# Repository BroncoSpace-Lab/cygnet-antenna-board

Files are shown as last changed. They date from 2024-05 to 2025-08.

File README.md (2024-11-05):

# antenna-board

This repo contains the KiCAD files for the PROVES Kit Antenna Board. This board currently goes on the +Z endcap of the satellite and hosts the antennas, interfacing ports, and some other support circuitry!

## antenna_top_cap_board_v1a
This antenna board is a reformat of the V1 Antenna Board that consolidates a bunch of the 2pos Picolock and STEMMA connectors into a single connector that runs back to the V3b EPS Board. We are probably going to leapfrog this version to land on V2 which fundementally changes things about the antenna feed path. 

## antenna_top_cap_v2
This version of the antenna top cap featuers major changes to the antenna feed path and debug passthroughs. Notable features are as follows: 
- Updated Balun Part Number (no longer sucks! still sucks to solder though)
- Addition of 12-pos and 5-pos Battery Board and Flight Controller Board debug connectors.

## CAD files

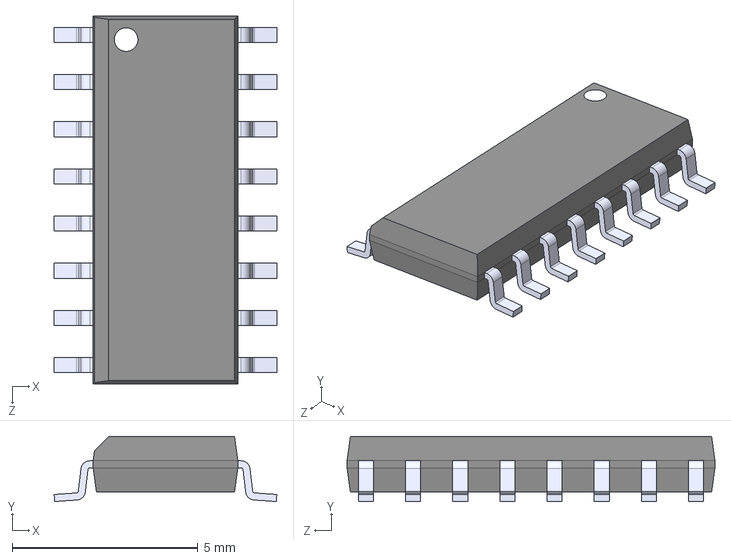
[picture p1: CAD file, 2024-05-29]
antenna_top_cap_v2b_cygnet_special/Extra Libraries Folder/CD74HC4050M96/CD74HC4050M96.step
5.99 x 1.75 x 9.91 mm

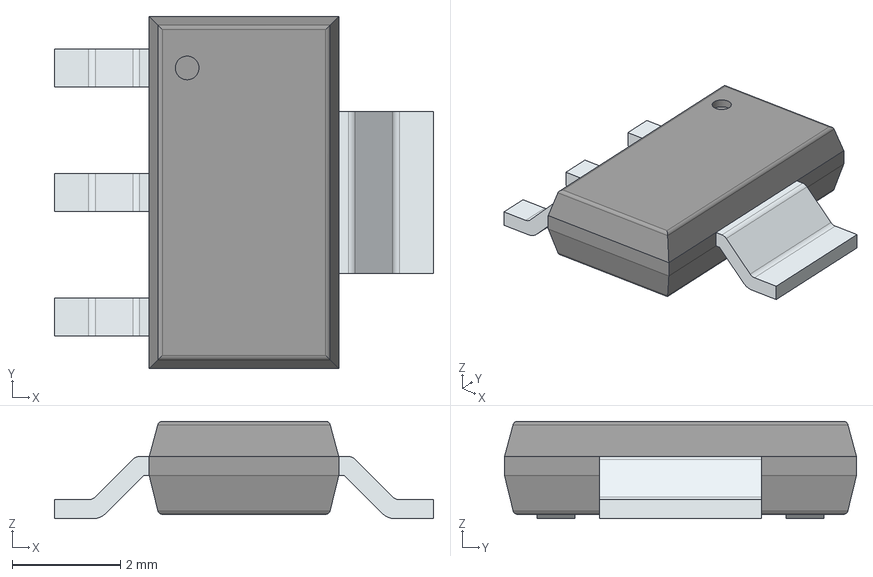
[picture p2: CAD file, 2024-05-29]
antenna_top_cap_v2b_cygnet_special/Extra Libraries Folder/LIB_AZ1117CH-3.3TRG1 (1)/AZ1117CH-3.3TRG1/3D/AZ1117CH-3.3TRG1.stp
7.00 x 6.50 x 1.80 mm
PinsArrayL
FilletPinR

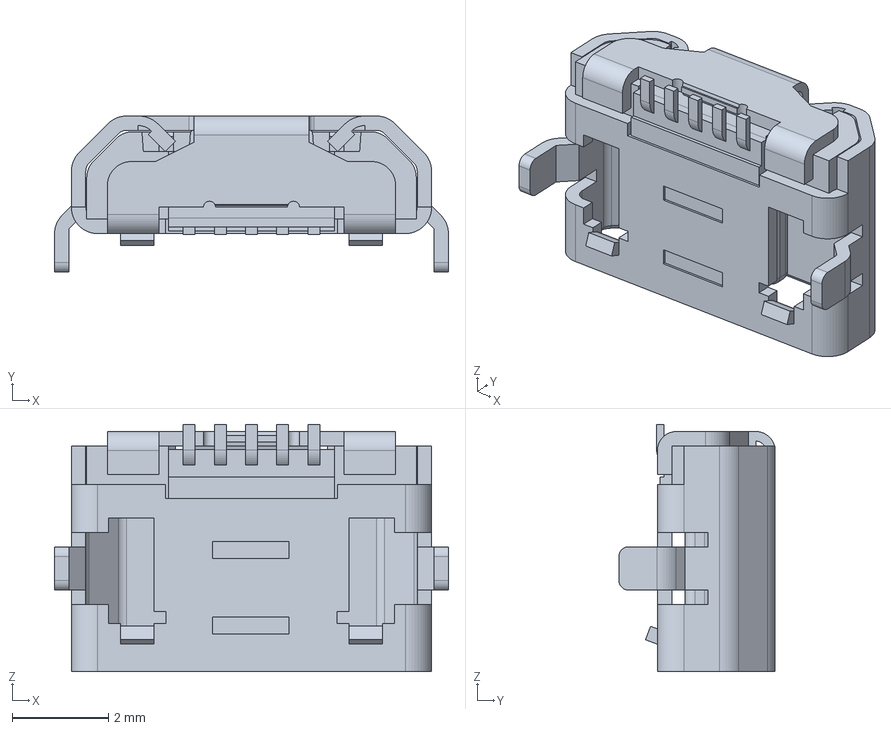
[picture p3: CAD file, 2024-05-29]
antenna_top_cap_v2b_cygnet_special/Extra Libraries Folder/105164-0001 (1)/105164-0001.step
8.20 x 3.25 x 5.15 mm

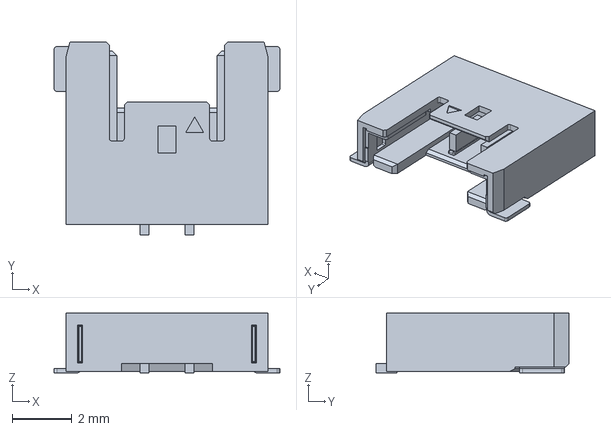
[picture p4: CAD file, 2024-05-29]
antenna_top_cap_v2b_cygnet_special/Extra Libraries Folder/504050-0291/504050-0291.step
7.55 x 6.44 x 2.00 mm

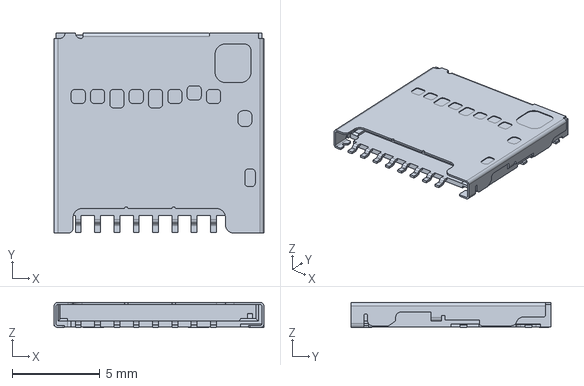
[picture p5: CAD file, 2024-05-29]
antenna_top_cap_v2b_cygnet_special/Extra Libraries Folder/LIB_104031-0811/104031-0811/3D/104031-0811.stp
11.9 x 11.4 x 1.45 mm

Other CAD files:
antenna_top_cap_v2b_cygnet_special/Extra Libraries Folder/LIB_104031-0811/104031-0811/Allegro/1040310811.psm
antenna_top_cap_v2b_cygnet_special/Extra Libraries Folder/LIB_104031-0811/104031-0811/DEHDL/104031_0811/chips/chips.prt
antenna_top_cap_v2b_cygnet_special/Extra Libraries Folder/LIB_AZ1117CH-3.3TRG1 (1)/AZ1117CH-3.3TRG1/Allegro/sot230p700x180-4n.psm
antenna_top_cap_v2b_cygnet_special/Extra Libraries Folder/LIB_AZ1117CH-3.3TRG1 (1)/AZ1117CH-3.3TRG1/DEHDL/az1117ch_3.3trg1/chips/chips.prt

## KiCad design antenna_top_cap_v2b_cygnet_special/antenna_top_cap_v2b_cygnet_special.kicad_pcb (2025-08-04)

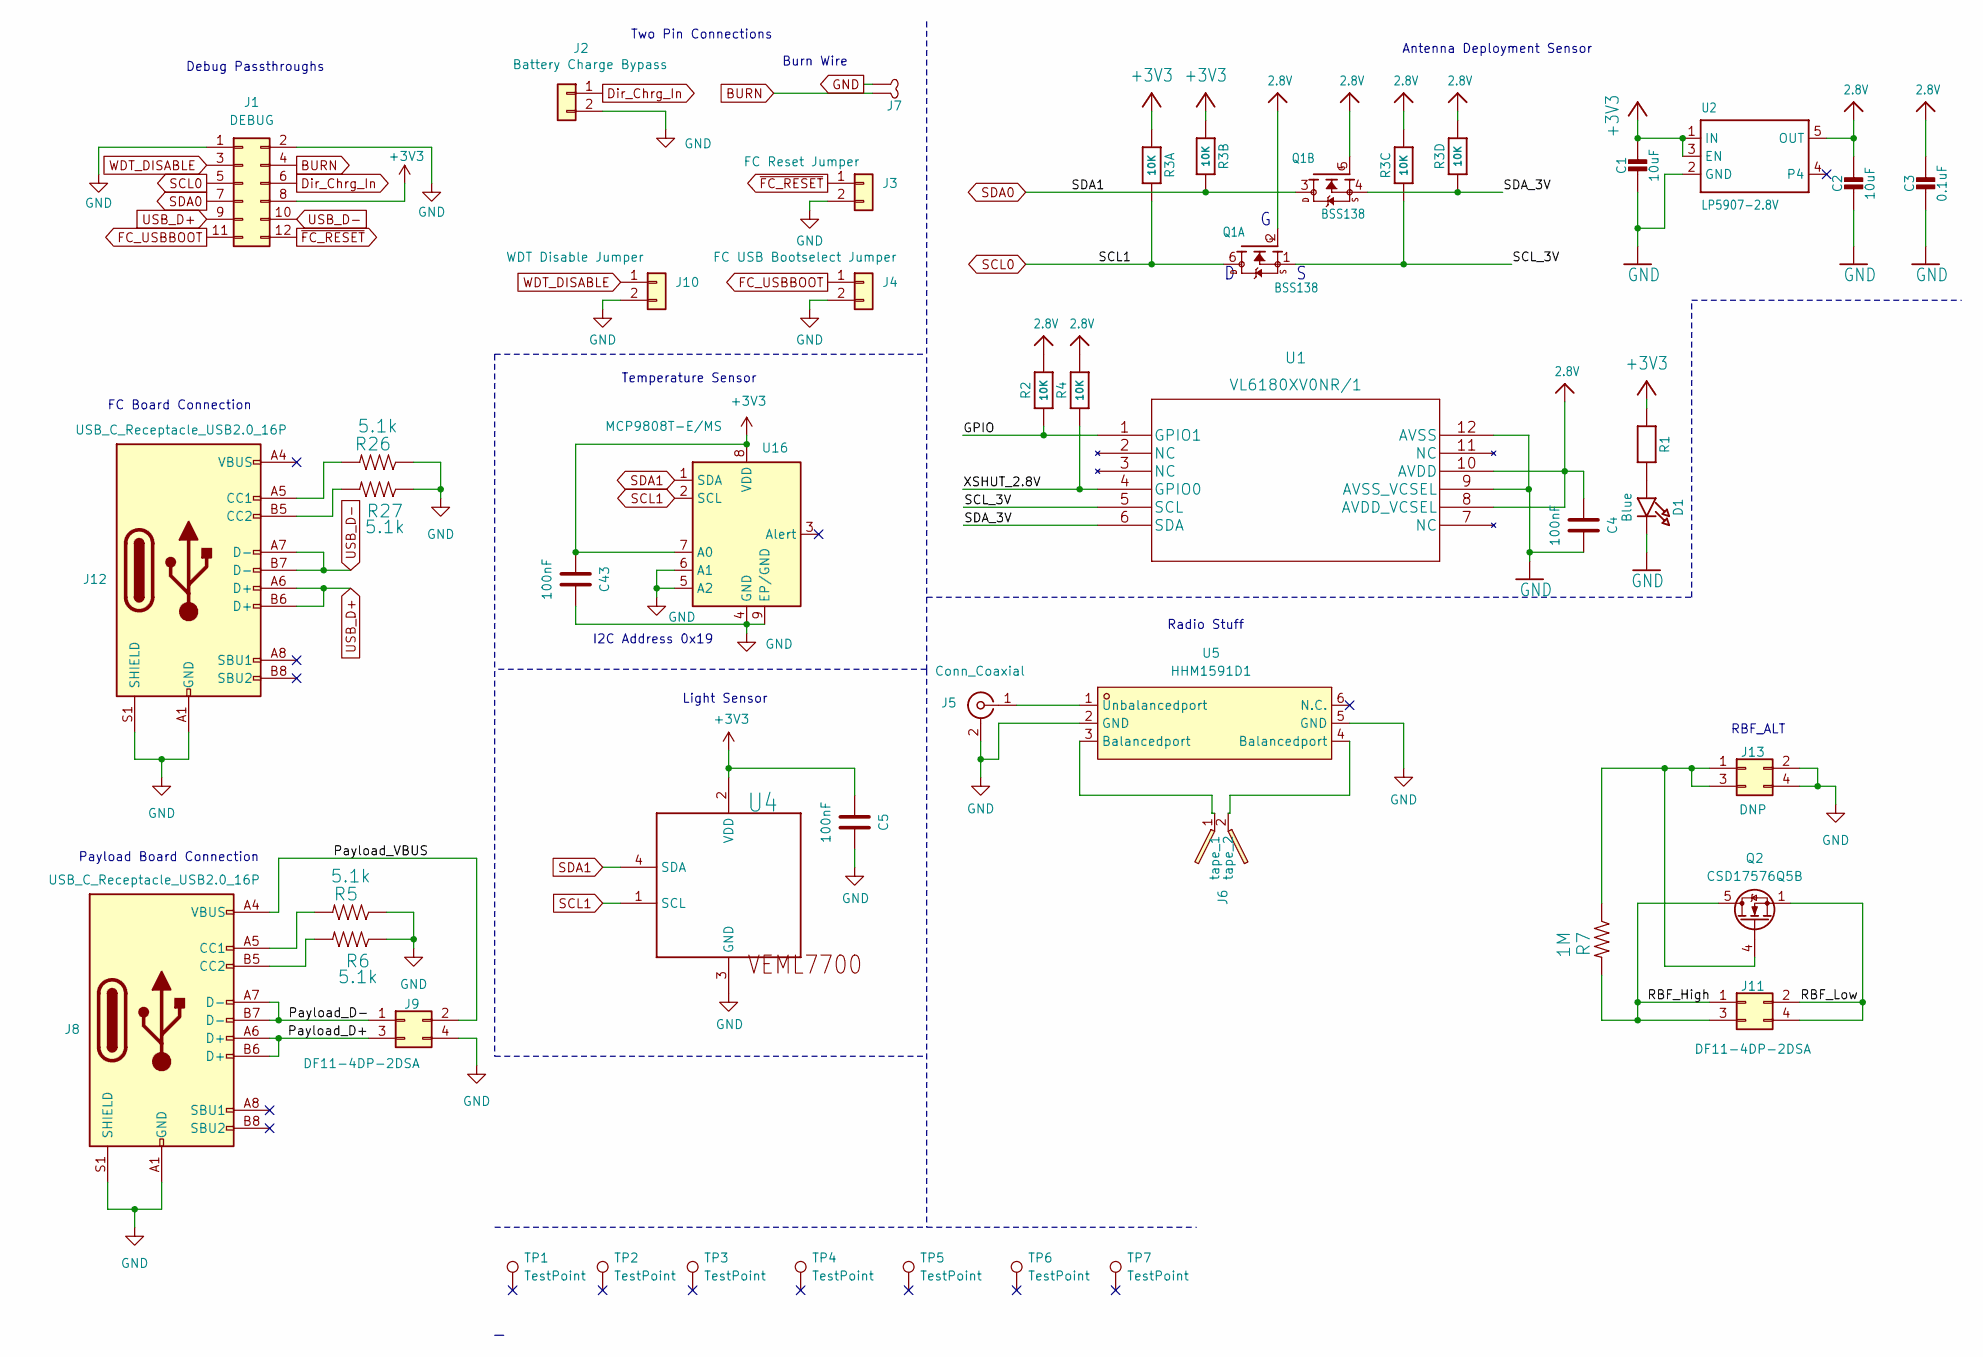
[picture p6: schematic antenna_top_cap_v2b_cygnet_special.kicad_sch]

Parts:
C1, C2: 10uF; C_0805_2012Metric
C3: 0.1uF; C_0603_1608Metric
C4, C5, C43: 100nF; C_0805_2012Metric
D1: Blue; LED_0603_1608Metric
J1: DEBUG; Hirose_DF11-12DP-2DSA_2x06_P2.00mm_Vertical
J2: Battery Charge Bypass; PinHeader_1x02_P2.54mm_Vertical
J3: FC Reset Jumper; PinHeader_1x02_P2.54mm_Vertical
J4: FC USB Bootselect Jumper; PinHeader_1x02_P2.54mm_Vertical
J5: Conn_Coaxial; SMA_Amphenol_901-144_Vertical
J6: Tape_Measure_Antenna
J7: Burn_Wire
J8, J12: USB_C_Receptacle_USB2.0_16P; USB_C_Receptacle_HRO_TYPE-C-31-M-12
J9, J11: DF11-4DP-2DSA; Hirose_DF11-4DP-2DSA_2x02_P2.00mm_Vertical
J10: WDT Disable Jumper; PinHeader_1x02_P2.54mm_Vertical
J13: DNP; Hirose_DF11-4DP-2DSA_2x02_P2.00mm_Vertical
Q1: BSS138; SOT-363_SC-70-6
Q2: CSD17576Q5B; TDSON-8-1
R1: 10k; R_0402_1005Metric
R2, R4: 10K; R_0603_1608Metric
R3: 10K; R_Array_Convex_4x0603
R5, R6, R26, R27: 5.1k; R_0603_1608Metric
R7: 1M; R_0603_1608Metric
TP1, TP2, TP3, TP4, TP5, TP6, TP7: TestPoint; MountingHole_2.7mm_M2.5_Pad
U1: VL6180XV0NR/1; VL6180
U2: LP5907-2.8V; SOT-23-5
U4: VEML7700; XDCR_VEML7700-TT
U5: HHM1591D1; XFMR-SMD_HHM1591D1; LCSC Part C74209
U16: MCP9808T-E/MS; MSOP-8-1EP_3x3mm_P0.65mm_EP1.5x1.8mm_ThermalVias

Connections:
2.8V: C2.1, C3.1, C4.1, Q1.2 (G), Q1.5 (G), R2.2, R3.3 (1), R3.4 (1), R4.2, U1.8 (AVDD_VCSEL), U1.10 (AVDD), U2.5 (OUT)
+3V3: C1.1, C5.1, C43.1, J1.8, R1.1, R3.1, R3.2 (1), U2.1 (IN), U2.3 (EN), U4.2 (VDD), U16.7 (A0), U16.8 (VDD)
/GPIO: R2.1, U1.1 (GPIO1)
/Payload_D+: J8.A6 (D+), J8.B6 (D+), J9.3
/Payload_D-: J8.A7 (D-), J8.B7 (D-), J9.1
/Payload_VBUS: J8.A4 (VBUS), J8.A9 (VBUS), J8.B4 (VBUS), J8.B9 (VBUS), J9.2
/RBF_High: J11.1, J11.3, Q2.5 (D), R7.2
/RBF_Low: J11.2, J11.4, Q2.1 (S), Q2.2 (S), Q2.3 (S)
/SCL_3V: Q1.1 (S), R3.6 (2), U1.5 (SCL)
/SDA_3V: Q1.4 (S), R3.5 (2), U1.6 (SDA)
/XSHUT_2.8V: R4.1, U1.4 (GPIO0)
BURN: J1.4, J7.1 (Power)
Dir_Chrg_In: J1.6, J2.1
FC_USBBOOT: J1.11, J4.1
GND: C1.2, C2.2, C3.2, C4.2, C5.2, C43.2, D1.2 (C), J1.1, J1.2, J2.2, J3.2, J4.2, J5.2 (Ext), J7.2 (GND), J8.A1 (GND), J8.A12 (GND), J8.B1 (GND), J8.B12 (GND), J8.S1 (SHIELD), J9.4, J10.2, J12.A1 (GND), J12.A12 (GND), J12.B1 (GND), J12.B12 (GND), J12.S1 (SHIELD), J13.2, J13.4, R5.1, R6.1, R26.1, R27.1, U1.9 (AVSS_VCSEL), U1.12 (AVSS), U2.2 (GND), U4.3 (GND), U5.2 (GND), U5.5 (GND), U16.4 (GND), U16.5 (A2), U16.6 (A1), U16.9 (EP/GND)
unnamed: D1.1 (A), R1.2
unnamed: J5.1 (In), U5.1 (Unbalancedport)
unnamed: J6.1 (tape), U5.3 (Balancedport)
unnamed: J6.2 (tape), U5.4 (Balancedport)
unnamed: J8.A5 (CC1), R5.2
unnamed: J8.B5 (CC2), R6.2
unnamed: J12.A5 (CC1), R26.2
unnamed: J12.B5 (CC2), R27.2
unnamed: J13.1, J13.3, Q2.4 (G), R7.1
SCL0: J1.5, Q1.6 (D), R3.8 (2), U4.1 (SCL), U16.2 (SCL)
SDA0: J1.7, Q1.3 (D), R3.7 (2), U4.4 (SDA), U16.1 (SDA)
USB_D+: J1.9, J12.A6 (D+), J12.B6 (D+)
USB_D-: J1.10, J12.A7 (D-), J12.B7 (D-)
WDT_DISABLE: J1.3, J10.1
~FC_RESET: J1.12, J3.1

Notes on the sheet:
Light Sensor
Two Pin Connections
I2C Address 0x19
Antenna Deployment Sensor
Radio Stuff
Debug Passthroughs
FC Board Connection
RBF_ALT
Payload Board Connection
Burn Wire
Temperature Sensor

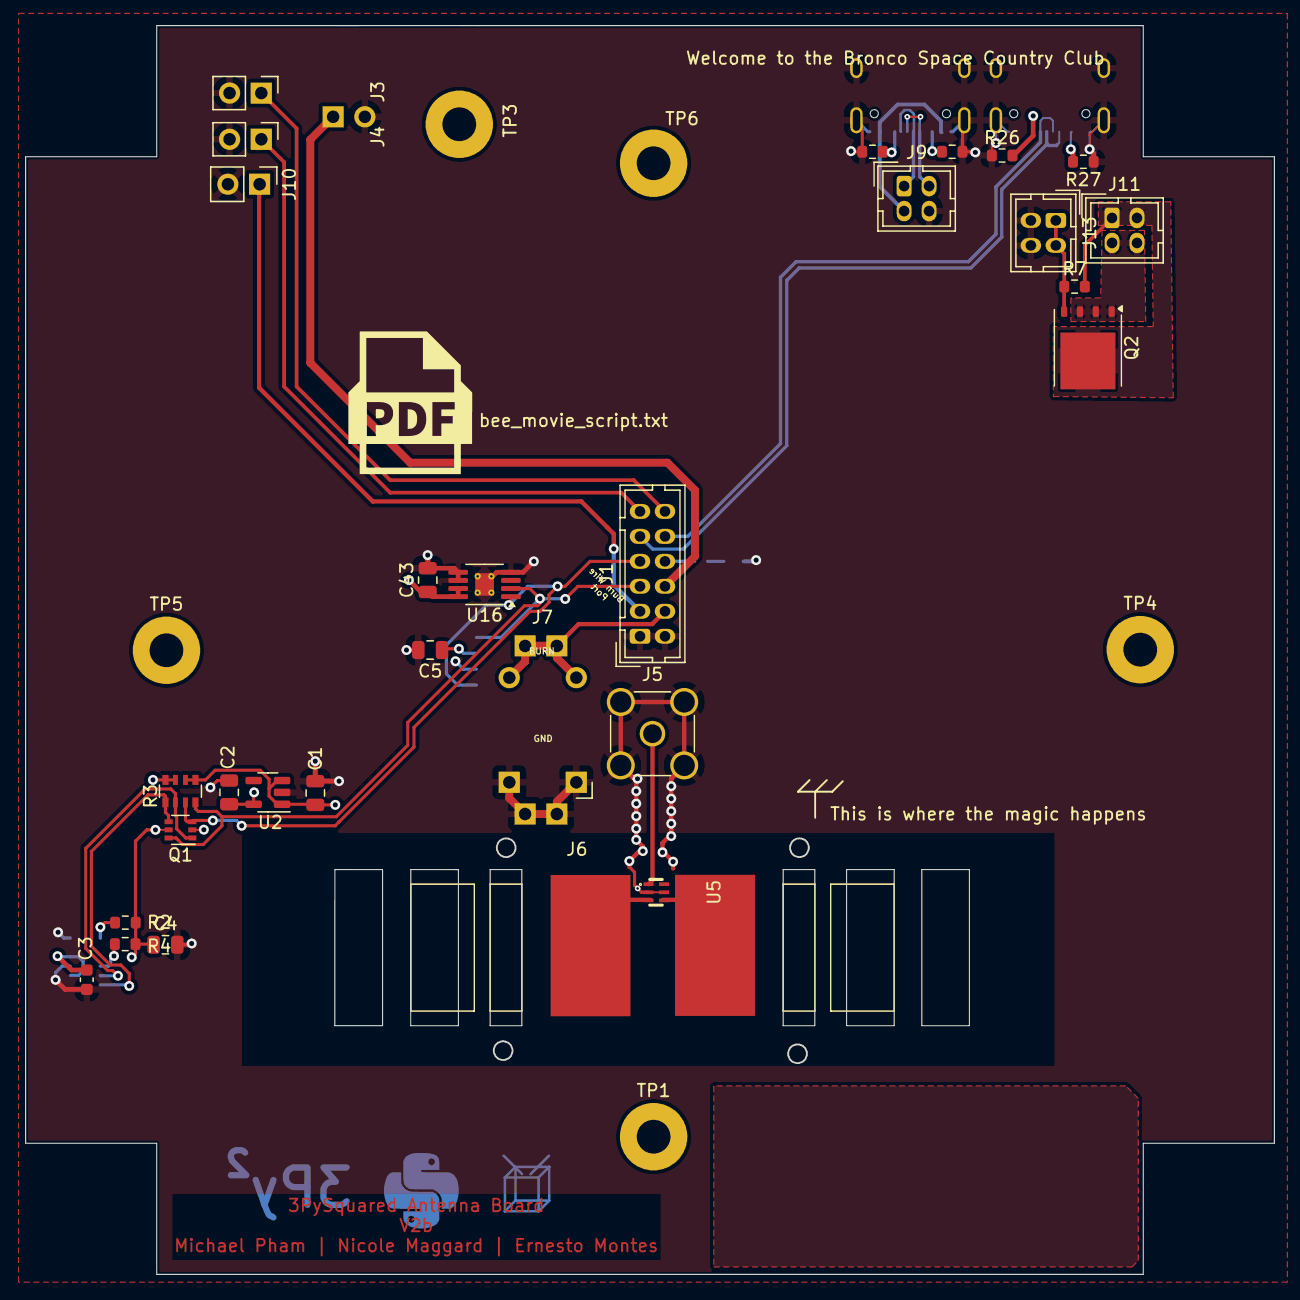
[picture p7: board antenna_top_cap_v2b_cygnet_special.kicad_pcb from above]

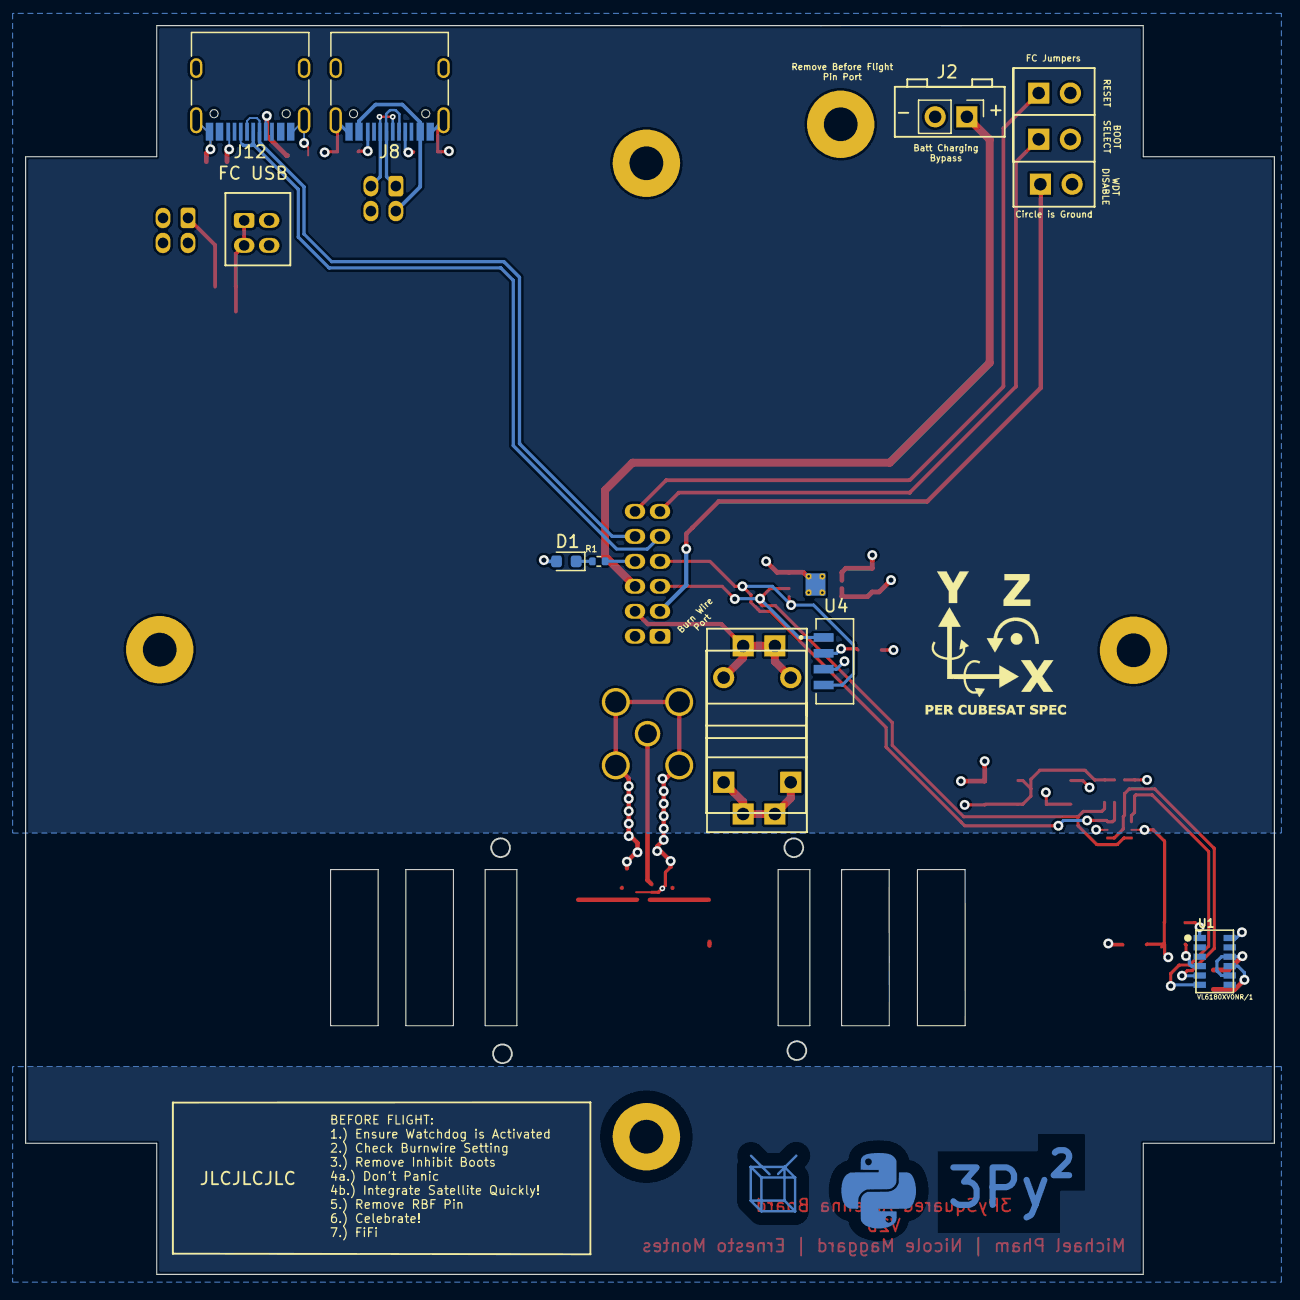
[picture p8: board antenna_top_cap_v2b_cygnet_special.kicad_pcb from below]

Board: 2 copper layers, 100.0 x 100.0 mm, 41 parts (7 on the bottom side), 30 nets.

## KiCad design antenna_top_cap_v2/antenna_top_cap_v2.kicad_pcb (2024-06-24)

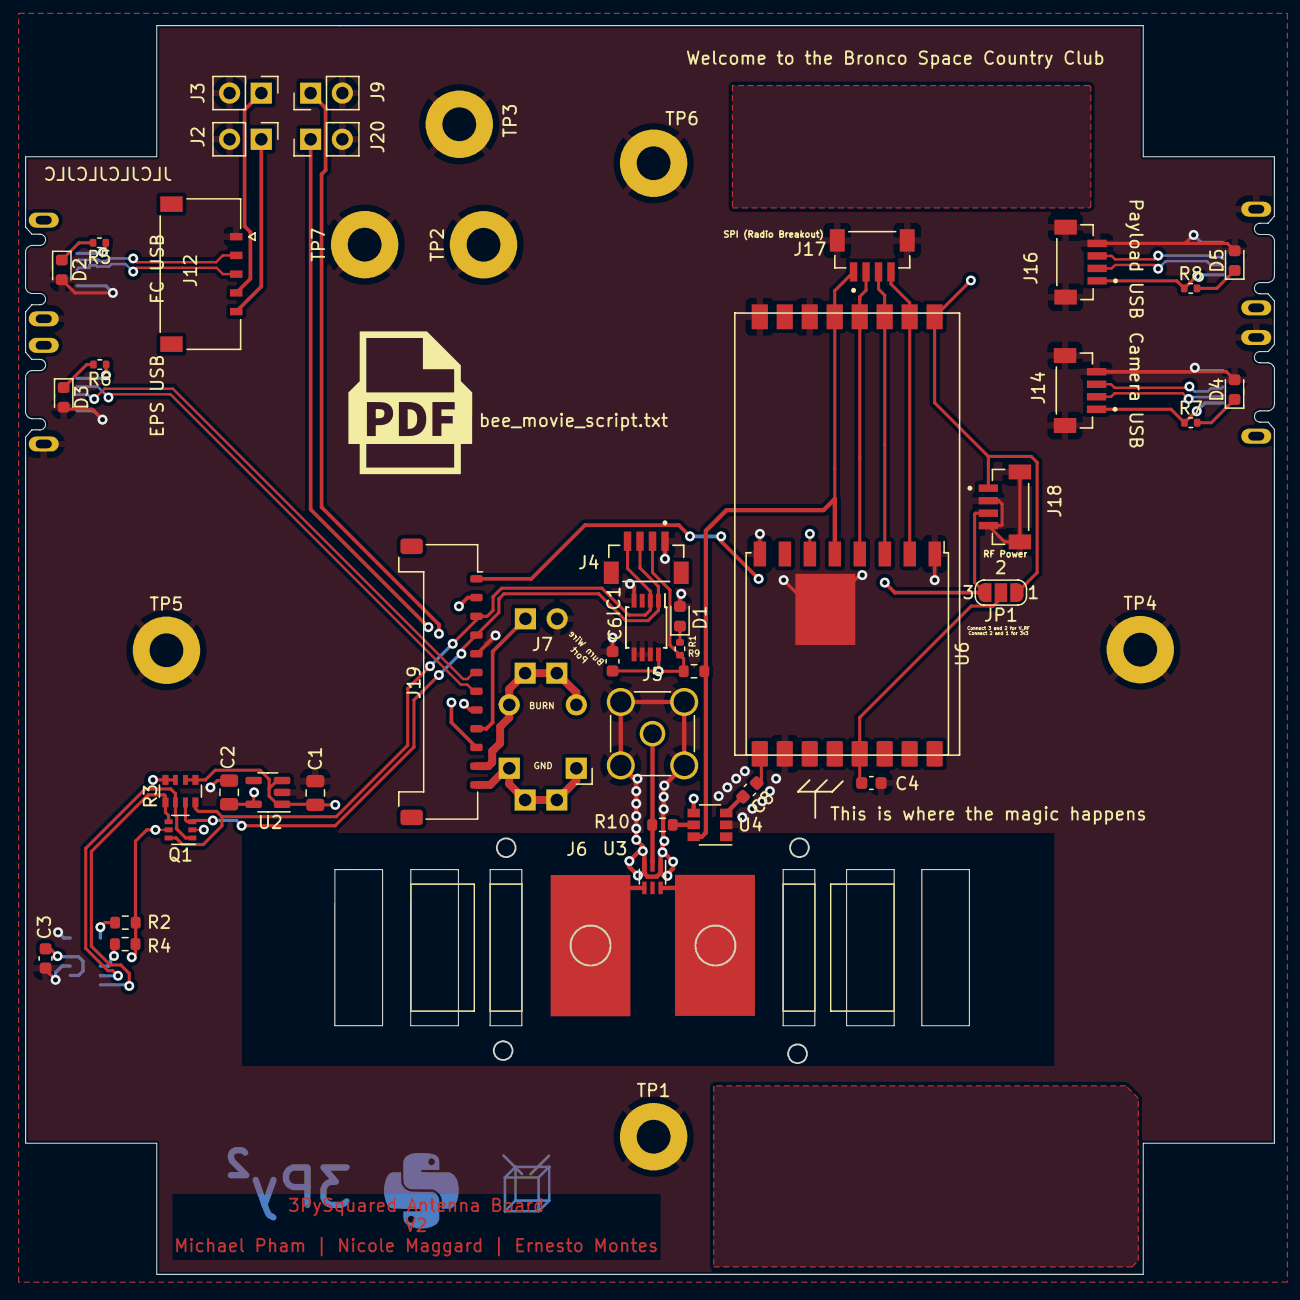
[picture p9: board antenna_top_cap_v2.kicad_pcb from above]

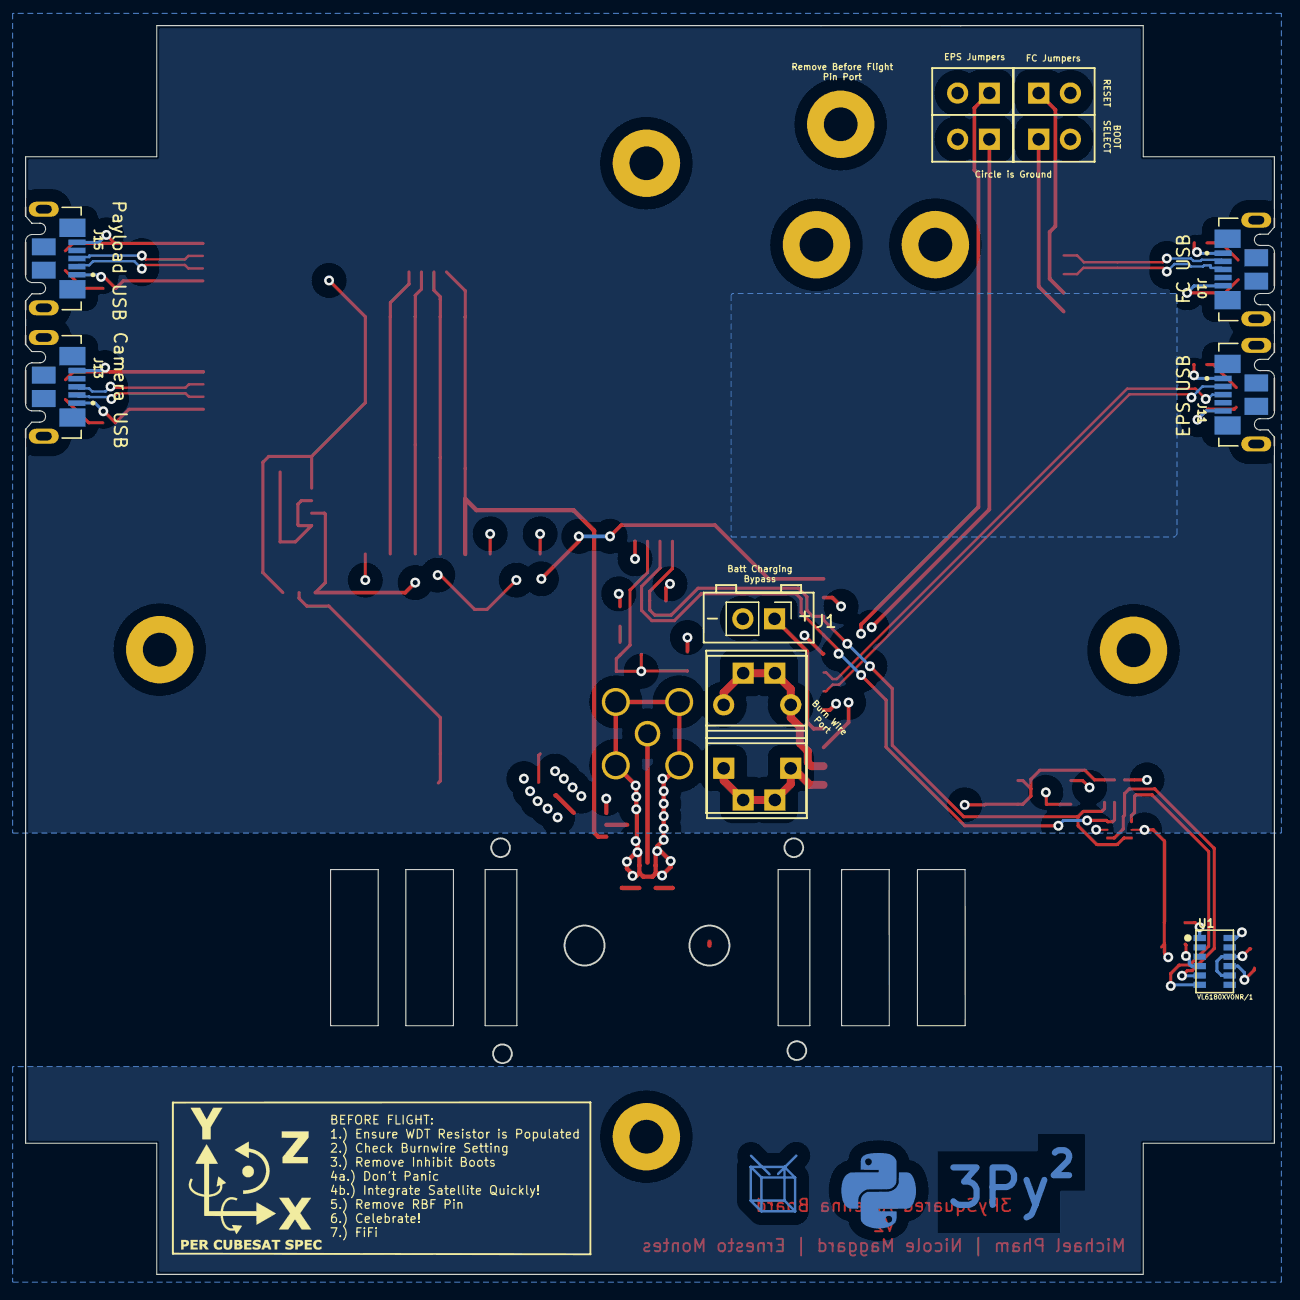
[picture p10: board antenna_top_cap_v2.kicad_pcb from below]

Board: 4 copper layers, 100.0 x 100.0 mm, 56 parts (6 on the bottom side), 45 nets.

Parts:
C1, C2: 10uF; C_0805_2012Metric
C3: 0.1uF; C_0603_1608Metric
C4: 10uF; C_0603_1608Metric
C6: 100nf; C_0603_1608Metric
C8: 100pf; C_0603_1608Metric
D1, D2, D3, D4, D5: Blue; LED_0603_1608Metric
IC1: PCT2075DP,118; TSSOP-8_3x3mm_P0.65mm
J1: Battery Charge Bypass; PinHeader_1x02_P2.54mm_Vertical
J2: EPS USB Bootselect Jumper; PinHeader_1x02_P2.54mm_Vertical
J3: EPS Reset Jumper; PinHeader_1x02_P2.54mm_Vertical
J4, J14, J16, J17, J18: BM04B-SRSS-TB(LF)(SN); JST_BM04B-SRSS-TB(LF)(SN)
J5: Conn_Coaxial; SMA_Amphenol_901-144_Vertical
J6: Tape_Measure_Antenna
J7: Burn_Wire
J9: FC Reset Jumper; PinHeader_1x02_P2.54mm_Vertical
J10: USB_B_Micro_FC; MOLEX_105164-0001(round)
J11: USB_B_Micro_EPS; MOLEX_105164-0001(round)
J12: FC Board Connector; MOLEX_5040500591
J13, J15: USB_B_Micro; MOLEX_105164-0001(round)
J19: EPS Board Connector; Molex_Pico-Lock_504050-1291_1x12-1MP_P1.50mm_Horizontal
J20: FC USB Bootselect Jumper; PinHeader_1x02_P2.54mm_Vertical
JP1: SolderJumper_3_Open; SolderJumper-3_P1.3mm_Open_RoundedPad1.0x1.5mm_NumberLabels
Q1: BSS138; SOT-363_SC-70-6
R1, R5, R6, R7, R8: 1K; R_0402_1005Metric
R2, R4: 10K; R_0603_1608Metric
R3: 10K; R_Array_Convex_4x0603
R9: 10k; R_0603_1608Metric
R10: DNI; R_0603_1608Metric
TP1, TP2, TP3, TP4, TP5, TP6, TP7: TestPoint; MountingHole_2.7mm_M2.5_Pad
U1: VL6180XV0NR/1; VL6180
U2: LP5907-2.8V; SOT-23-5
U3: NCS1.5-232+; Balun_Johanson_0896BM15A0001
U4: AS193-73LF; SuperSOT-6
U5: RFM98PW
U6: RFM9xBreakout; HOPERF_RFM95W_SMD

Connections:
2.8V: C2.1, C3.1, Q1.2 (G), Q1.5 (G), R2.2, R3.3 (1), R3.4 (1), R4.2, U1.8 (AVDD_VCSEL), U1.10 (AVDD), U2.5 (OUT)
+3V3: C1.1, C6.1, IC1.8 (VCC), J4.2, J18.1, J19.2, JP1.1 (A), R1.1, R3.1, R3.2 (1), R9.1, U2.1 (IN), U2.3 (EN), U4.4 (V2), U5.9 (3.3V), U6.6 (~RESET)
/2d+: J13.3 (D+), J14.3
/2d-: J13.2 (D-), J14.2
/3d+: J15.3 (D+), J16.3
/3d-: J15.2 (D-), J16.2
/GPIO: R2.1, U1.1 (GPIO1)
/SCL_3V: Q1.1 (S), R3.6 (2), U1.5 (SCL)
/SDA_3V: Q1.4 (S), R3.5 (2), U1.6 (SDA)
/XSHUT_2.8V: R4.1, U1.4 (GPIO0)
BURN: J7.1 (Power), J19.11
BURN_GND: J7.2 (GND), J19.12
Balun: R10.1, U4.5 (output)
Dir_Chrg_In: J1.1, J19.9
EPS_USBBOOT: J2.1, J19.10
EPS_USB_D+: J11.3 (D+), J19.6
EPS_USB_D-: J11.2 (D-), J19.7
FC_USBBOOT: J12.5, J20.1
FC_USB_D+: J10.3 (D+), J12.3
FC_USB_D-: J10.2 (D-), J12.2
GND: C1.2, C2.2, C3.2, C4.1, C6.2, D1.2 (C), D2.2 (C), D3.2 (C), D4.2 (C), D5.2 (C), IC1.4 (GND), IC1.5 (A2), IC1.6 (A1), IC1.7 (A0), J1.2, J2.2, J3.2, J4.1, J5.2 (Ext), J9.2, J10.5 (GND), J10.SH1 (Shield), J11.5 (GND), J11.SH1 (Shield), J12.1, J13.5 (GND), J13.SH1 (Shield), J14.4, J14.S1 (SHIELD), J14.S2 (SHIELD), J15.5 (GND), J15.SH1 (Shield), J16.4, J16.S1 (SHIELD), J16.S2 (SHIELD), J17.S1 (SHIELD), J17.S2 (SHIELD), J18.2, J18.4, J18.S1 (SHIELD), J18.S2 (SHIELD), J19.5, J20.2, TP1.1, TP2.1, TP3.1, TP4.1, TP5.1, TP6.1, TP7.1, U1.9 (AVSS_VCSEL), U1.12 (AVSS), U2.2 (GND), U3.1 (GND), U3.3 (GND), U4.2 (GND), U5.2 (GND), U5.14 (RESET), U5.16 (GND), U5.17 (GND), U6.1 (GND), U6.8 (GND), U6.10 (GND)
unnamed: D1.1 (A), R1.2
unnamed: D2.1 (A), R5.2
unnamed: D3.1 (A), R6.2
unnamed: D4.1 (A), R7.2
unnamed: D5.1 (A), R8.2
unnamed: J5.1 (In), R10.2, U3.2
unnamed: J6.1 (tape), U3.4
unnamed: J6.2 (tape), U3.6
unnamed: J10.1 (VBUS), R5.1
unnamed: J11.1 (VBUS), R6.1
unnamed: J13.1 (VBUS), J14.1, R7.1
unnamed: J15.1 (VBUS), J16.1, R8.1
unnamed: C8.2, U4.3 (input2)
OUT2: C8.1, U5.1 (ANT), U6.9 (ANT)
RF_VCC: C4.2, JP1.2 (C), U5.5 (VCC), U6.13 (3V3)
SCL1: IC1.2 (SCL), J4.4, J19.3, Q1.6 (D), R3.8 (2)
SDA1: IC1.1 (SDA), J4.3, J19.4, Q1.3 (D), R3.7 (2)
SPI0_CS0: J17.1, R9.2, U4.6 (V1), U5.13 (NSS), U6.5 (CS)
SPI0_MISO: J17.4, U5.10 (MISO), U6.2 (MISO)
SPI0_MOSI: J17.3, U5.11 (MOSI), U6.3 (MOSI)
SPI0_SCK: J17.2, U5.12 (SCK), U6.4 (SCK)
V_RF: J18.3, J19.1, JP1.3 (B)
~EPS_RESET: J3.1, J19.8
~FC_RESET: J9.1, J12.4

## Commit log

2024-06-13 Started wiring with 12-pos connector for V3b
    [antenna_top_cap.kicad_pcb, antenna_top_cap.kicad_sch]
2024-06-15 Scooted IC Layout
    [antenna_top_cap.kicad_pcb]
2024-06-17 Update antenna_top_cap.kicad_pcb
    Connected Direct Change to the 12 Pin Picolock
    [antenna_top_cap.kicad_pcb]
2024-06-17 Connected USB Breakout
    [antenna_top_cap.kicad_pcb, antenna_top_cap.kicad_sch]
2024-06-17 Finished Connecting 12Pos Connections
    [antenna_top_cap.kicad_pcb, antenna_top_cap.kicad_sch]
2024-06-17 Addressed all DRC Errors
    [antenna_top_cap.kicad_pcb, antenna_top_cap.kicad_sch]
2024-06-17 Added Jumper to Aux RF Line
    Added an 0603 Jumper to break the Aux RF connection when not in use
    [antenna_top_cap.kicad_pcb, antenna_top_cap.kicad_sch]
2024-06-18 Relocated RF SPI Breakout
    [antenna_top_cap.kicad_pcb]
2024-06-18 Removed redundant trace
    For some reason there was both a 2.8V trace on the F.Cu and the B.Cu layers. Might be an artifact of the original design. The trace on the B.Cu layer was removed
    [antenna_top_cap.kicad_pcb]
2024-06-18 Updated Solder Mask
    [antenna_top_cap.kicad_pcb]
2024-06-18 Created V2 Antenna Board
    [104031-0811.SchLib, 104031-0811.stp, 1040310811.PcbLib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]
2024-06-19 Schematic Updates and Renaming a Bunch of Files
    [104031-0811.SchLib, 104031-0811.stp, 1040310811.PcbLib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]
2024-06-19 Un-nested files
    [104031-0811.SchLib, 104031-0811.stp, 1040310811.PcbLib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]
2024-06-19 Swapped Balun
    New Balun Part Number!
    Minicircuits: NCS1.5-232+
    Schematic and PCB Layout Updated
    [antenna_top_cap_v2.kicad_pcb, antenna_top_cap_v2.kicad_sch]
2024-06-19 Added Schematic Symbols for FC Debug Port
    [antenna_top_cap_v2.kicad_pcb, antenna_top_cap_v2.kicad_sch]
2024-06-20 SDA / SCL Hotfix
    See this issue: https://github.com/proveskit/antenna-board/issues/6
    [antenna_top_cap_v2.kicad_pcb, antenna_top_cap_v2.kicad_sch]
2024-06-20 Removed J8 (I2C Breakout)
    [antenna_top_cap_v2.kicad_pcb, antenna_top_cap_v2.kicad_sch]
2024-06-20 fixed the schematic
    cool beans
    [antenna_top_cap_v2.kicad_pcb, antenna_top_cap_v2.kicad_sch]
2024-06-23 Removed One of the I2C Breakouts
2024-06-23 Added mounting hole keep out areas
2024-06-23 Completed LiDAR Layout
    [antenna_top_cap_v2.kicad_sch]
2024-06-24 Finished On Board Placements
2024-06-24 Completed Layout
    [antenna_top_cap_v2.kicad_sch]
2024-06-24 As Ordered June 23, 2023
    [antenna_top_cap_v2-CuBottom.gbr, antenna_top_cap_v2-CuIn1.gbr, antenna_top_cap_v2-CuIn2.gbr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]
2024-06-24 Updated BOM
    [antenna_top_cap_v2.kicad_pcb]
2025-04-15 Created V2a Project
    [104031-0811.SchLib, 104031-0811.stp, 1040310811.PcbLib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]
2025-04-16 Deleted Unused Parts
    [antenna_top_cap_v2a.kicad_pcb, antenna_top_cap_v2a.kicad_sch]
2025-04-16 Added USB and DF11 Debug Connector
    [antenna_top_cap_v2a.kicad_pcb, antenna_top_cap_v2a.kicad_sch]
2025-04-16 Added MCP Temperature Sensor
    [antenna_top_cap_v2a.kicad_pcb, antenna_top_cap_v2a.kicad_sch]
2025-04-17 Added VEML7700 Light Sensor
    [antenna_top_cap_v2a.kicad_pcb, antenna_top_cap_v2a.kicad_sch]
2025-04-18 Production Files as Ordered 4/17/2025
    [antenna_top_cap_v2a-CuBottom.gbr, antenna_top_cap_v2a-CuIn1.gbr, antenna_top_cap_v2a-CuIn2.gbr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]
2025-05-03 Corrected BOM Error
    The 5.1K USB-C Resistors were not populated by accident on the first production run.
    [antenna_top_cap_v2a-CuBottom.gbr, antenna_top_cap_v2a-CuIn1.gbr, antenna_top_cap_v2a-CuIn2.gbr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]
2025-07-16 Updated Impedance of USB Traces
    [104031-0811.SchLib, 104031-0811.stp, 1040310811.PcbLib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]
2025-07-16 Added Payload USB Passthrough
    [antenna_top_cap_v2b.kicad_pcb, antenna_top_cap_v2b.kicad_sch]
2025-07-30 Redid USB Trace Impedance
    [antenna_top_cap_v2b.kicad_pcb, antenna_top_cap_v2b.kicad_sch]
2025-07-31 Added Alt RBF
    [antenna_top_cap_v2b.kicad_pcb, antenna_top_cap_v2b.kicad_sch]
2025-08-04 Initial Board
    [104031-0811.SchLib, 104031-0811.stp, 1040310811.PcbLib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]
2025-08-04 As Ordered Aug 4 2025
    [antenna_top_cap_v2b_cygnet_special-CuBottom.gbr, antenna_top_cap_v2b_cygnet_special-CuIn1.gbr, antenna_top_cap_v2b_cygnet_special-CuIn2.gbr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]
